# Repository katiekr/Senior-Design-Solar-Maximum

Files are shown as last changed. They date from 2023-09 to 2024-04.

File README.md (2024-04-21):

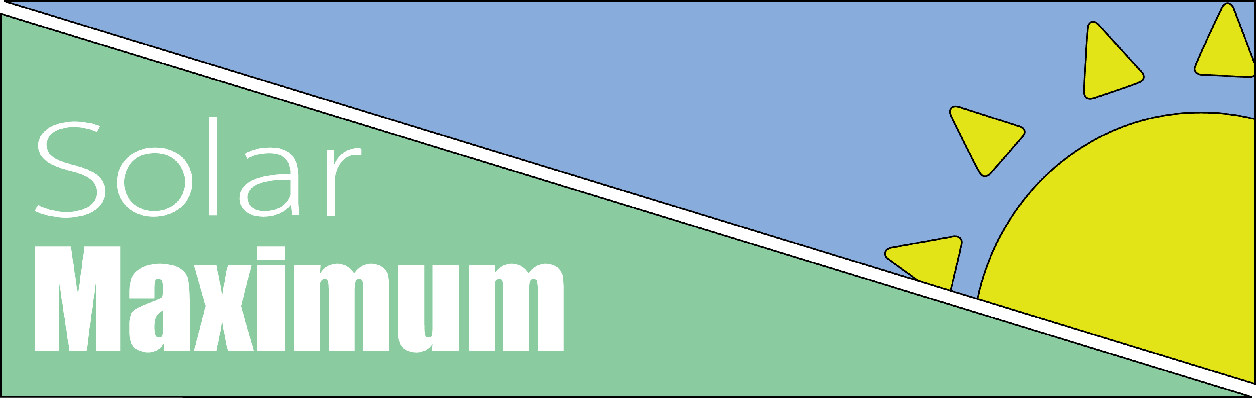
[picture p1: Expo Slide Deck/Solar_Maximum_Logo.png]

# Senior-Design-Solar-Maximum
[Team names (include Advisor) and Project Abstract](https://github.com/cabledc/Senior-Design-Solar-Maximum/blob/main/Team%20Info/Project%20and%20Group%20Members.md)

Project Description: Suntracking based on current input from a solar panel.

## First Semester

[Professional Biographies](https://github.com/cabledc/Senior-Design/tree/main/Biographies)

[User Stories](https://github.com/cabledc/Senior-Design/blob/main/Design/User_Stories.md)

[General Design Diagrams](https://github.com/cabledc/Senior-Design/tree/main/Design)

[Old Circuit Design Diagrams](https://github.com/cabledc/Senior-Design/tree/main/Design/Circuits)

[Project Tasks and Timeline (First Semester)](https://github.com/cabledc/Senior-Design/blob/main/Planning/Tasklist.md)

[ABET Concerns Essay](https://github.com/cabledc/Senior-Design/blob/main/Planning/Constraints%20(Assignment%207))

[PPT Slideshow Presentation (First Semester)](https://youtu.be/Y3RMfyllHsM)

[Self-Assessment Essays](https://github.com/cabledc/Senior-Design/tree/main/Team%20Info/Individual%20Capstone%20Assessments)

## Second Semester

[Updated Circuit Design Diagrams](https://github.com/cabledc/Senior-Design-Solar-Maximum/tree/main/Design/Circuits/Updated)

[Final Slideshow](https://www.youtube.com/watch?v=uT7PXCWO-sI)

[Expo Poster](https://github.com/cabledc/Senior-Design-Solar-Maximum/blob/main/Expo%20Slide%20Deck/Poster/Final%20Poster.pdf)

[Testing and Video Demos](https://github.com/cabledc/Senior-Design-Solar-Maximum/tree/main/Testing%20Logs)

[Budget](https://github.com/cabledc/Senior-Design/blob/main/Planning/Budget)

[Final Self-Assessments](https://github.com/cabledc/Senior-Design-Solar-Maximum/tree/main/Team%20Info/Self%20Assessments)

[Appendix and Committed Hours](https://github.com/cabledc/Senior-Design/blob/main/Planning/Appendix.md)

### User Documentation
[Hardware Setup (Start Here)](https://github.com/cabledc/Senior-Design-Solar-Maximum/blob/main/User%20Documentation/Hardware%20Setup.md)  

[Software Setup](https://github.com/cabledc/Senior-Design-Solar-Maximum/blob/main/User%20Documentation/Software%20Setup.md)  

[3D Printed Motor/Panel Adapter](https://github.com/cabledc/Senior-Design-Solar-Maximum/blob/main/User%20Documentation/3D%20Printed%20Housing%20Setup.md)  

[FAQ](https://github.com/cabledc/Senior-Design-Solar-Maximum/blob/main/User%20Documentation/FAQ.md)

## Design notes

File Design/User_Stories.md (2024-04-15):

- As the lead engineer for a green energy company, I want our solar panels to track the sun's position, so we can maximize the energy output and efficiency per panel.

- As a solar energy customer, I have limited area for a solar panel installation, so the panels should get as much sunlight as possible throughout the day.

- As a material scientist, I need ways of increasing output of our current solar cells, without using more expensive materials.

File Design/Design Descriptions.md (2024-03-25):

## Design Diagram Descriptions

## Design 1 Simple diagram of the system loop
  - Input 
    - Solar energy
  - Output
    - Panel Orientation

## Design 2 Shows computation and energy storage integration
  - Input 
    - Solar energy
    - Arduino
    - battery
  - Output
    - Arduino
    - Panel Rotation
    - Battery

## Design 3 Shows computation the algorithm inputs and outputs, energy storage and management, and how the feedback loop operates.
  - Input
    - Solar energy
    - Electricity measurement to arduino
    - Arduino
    - Battery
    - Charge Controller

  - Output
    - Arduino
    - Positioning/Tracking Algorithm Output
    - Panel Rotation
    - Feedback loop that maximizes solar energy
    - Battery
    - Charge Controller

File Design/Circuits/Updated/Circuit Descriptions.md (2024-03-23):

### Here you will find iterative circuit designs to progress testing our hardware components. These include: ###
- Testing the Current Reader Adafruit INA219 5v, which is the most important component, as it is getting data from the solar panel's current. We need to insure it is sensitive enough to detect changes in current.
  - >Note: ACS712 5v was tested in the old diagrams, it was not sensitive enough for accurate data.
- Testing the stepper motor. This is to get an initial positioning algorithm working, and see how different steps correspond to the angle of rotation.
  - >Note: steppers replaced servos because of the rotation limits on servos, as well as the lack of rotational accuracy.
- Testing with final prototype, this tests the charge controller and powers everything without a pc hookup.

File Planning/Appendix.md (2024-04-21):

# (Senior Design Part 1)
## What has been done:
  ### Hardware
  All the correct hardware has been acquired and the circuits have been designed. The hardware has been researched to match the specs of our design, (voltage, wattage, etc).
- We have found we needed a charge controller instead of connecting a battery directly to the solar panel. Otherwise this would have damaged the battery.
- Stepper motors were switched for servo motors. As stepper motors require constant charge, even when not moving. They also each require a control board making the circuit more complicated.
- Powering arduino components from the charge controller, instead of the arduino directly. Servo motors can spike in amps and potentially cut power from the arduino. Connecting everything to the main power supply (charge controller) prevents this.
- The Current reader applies zero load, so the initial circuit would have shorted and damaged the panel. A 220ohm resistor + LED was added for a load to prevent this.

  ### Software
- We have found supporting libraries exist for the arduino components we are using. These can be imported to allow faster interfacing with the components
  - Research on PID implementation. This will smooth jumpy/uneven output from an algorithm that is adjusting servo position(s).

### What still needs to be done next semester (In Order):
- Hardware prototype assembly.
- Arduino software implementation. And initial component interface testing.
- Each circuit (already designed) will be tested. There are 3, each one is more complex, but allows for a step by step process for testing. Leading to the final circuit.
- 3D printing of housing for the prototypes, if needed.

# (Senior Design Part 2)
### Hardware
After testing servo motors, we realized they cannot do a full 360 degree rotation. There was also no way to keep an accurate measurement of their movement. So we had to switch back to using a stepper motor instead. This allows us to keep track of steps and store information on energy recieved in each direction. As well as providing info for an untangle function.

We switched to Adafruit INA219 for current measurement as it provided higher resolution data, and allowed the device to work indoors with a flashlight. The ACS712 module was not sensitive enough for the low voltages we were using. More info can be found in the testing log summary [Current Testing](https://github.com/cabledc/Senior-Design-Solar-Maximum/blob/main/Testing%20Logs/Testing%20Logs%202-14-22.md)

The circuit diagrams had to be updated as well and can be found here [Updated Circuits](https://github.com/cabledc/Senior-Design-Solar-Maximum/tree/main/Design/Circuits/Updated)

A 3D printed holder for the solar panel and stepper motor mount was created. Those files can be found here [3D Prints](https://github.com/cabledc/Senior-Design-Solar-Maximum/tree/main/3D%20Printer%20Files)

### Software
3 Versions of the software are provided along with the testing for the deprecated ACS712 module (switched for Adafruit INA219). Each tracking code release improves on the previous version. The algorithm does not use a PID controller as this didn't quite fit the data and scenario we were trying to use it for. There are 3 main variables that control the new algorithm:
- int addSteps = 2;
  - Positive feedback when the rate of increase is greater than the previous rate of increase, adds steps to move the panel further in its current direction
- int divideSteps = 4;
  - Negative feedback when the rate of increase is less than the previous rate of increase, divides steps to slow the panels movement and increase measurement frequency. Once this is less than 2 the panel stops.
- int startingSteps = 40;
  - Initial movement check, in each direction. A full rotation is 2048 steps.

---
 
### Overall Listed Objectives Summmary:
- General design and project outline(October)
- Hardware planning and research(November)
- Circuit Design (December)
- Build first test prototype(February)
- Interface components with Arduino IDE(February)
- Mechanical Prototype Development/Testing(End of February)
  - Testing sensors, software calibration and filtering of raw data from the sensors.
  - Ensuring all components are tested and operate correctly and accurately
- Arduino Software Development(March)
  - Use the filtered sensor data to develop code to move the stepper with the attached solar panel

---

### Work Division (Second Semester)
> Destry Cable 91hrs
- Prototype Devlopment 86hrs
  - 3D Printing 8hrs
  - Circuit Redesign 10hrs
  - Code Development 30hrs
  - Testing 30hrs
  - Soldering and wire management 8hrs
- Expo Presenting 5hrs
    
> Katherine Kraus 45hrs
- Testing Planning 15hrs
- Slides and Presenting 10hrs
- Expo Presenting 5hrs
- Meetings/Communication 10hrs
  
> Alexander Miller 45hrs
- Logo and Poster Design 25hrs
- Meetings/Communication 10hrs
- Expo Presenting 5hrs

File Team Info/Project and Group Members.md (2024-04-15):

## Team Members
> Destry Cable - cabledc@mail.uc.edu

> Katherine Kraus - krauskr@mail.uc.edu

> Alexander Miller - mille8ae@mail.uc.edu

> Acting Advisor - Prof Zhao Yu

## Project Abstract
Our senior design project focuses on enhancing solar energy efficiency through a sun tracking system controlled by Arduino. By continuously adjusting solar panel orientation to follow the sun's path, our project aims to optimize energy output. 
We will develop an Arduino based control system that calculates the sun's position, while a mechanical system with sensors ensures accurate alignment. We will also implement energy monitoring and data logging to assess system performance. 
This project seeks to make solar power more efficient, contributing to sustainable energy solutions.

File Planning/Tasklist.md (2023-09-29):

|Project Tasks|  |Assigned Members|  |Date|

-Task 1           Katherine           10/15/23
Research Motors for tilt and rotation

-Task 2           Katherine           10/15/23
Research Battery needed

-Task 3           Katherine           10/15/23
Research Solar Panel needed
(5x5 inches max)

-Task 4           Katherine           10/15/23
Research component(s) for measuring electricity input on the arduino

-Task 5           Katherine           10/22/23
General circuit design and components
Create a detailed circuit design file with all the components included

-Task 6           Destry              10/29/23
Get tools needed, order components

-Task 7           Alexander,Destry    11/5/23
Arduino program outline 
Algorithm for moving motors based on input
PID inputs and use if needed
Feedback loop design

-Task 8           Destry              11/12/23     
Assembly of circuit and components
soldering etc.

-Task 9           Destry              11/19/23
3D printing housing and design
Programs needed, and types of files used

-Task 10          Alexander,Destry,Katherine  11/26/23
Final testing and refinement
Testing and refining arduino code on assembled components
Refining/optimizing various components

-Task 11          Alexander,Destry,Katherine  End of Semester
Final Presentation
Slides and recording

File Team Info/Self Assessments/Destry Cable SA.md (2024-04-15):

My individual contribution to this project was being the team leader/manager, and
 lead developer. I was responsible for developing the code base for the software. This
 includes filtering data input and developing the algorithm to feed the data into. Which
 controls the solar panel position by applying input to the stepper motor.
 
 The skills I built upon were learning how to interface with hardware through
 arduino code. Designing circuits, which I had little experience in. As well as getting a
 better understanding of how solar panels operate. This includes an understanding of
 how their electrical data output correlates with their position to a light source. I ran into
 many issues during the project. They were all hardware related. Some examples
 include the initial current sensor used was not sensitive enough. The servo motors were
 also not accurate with positioning, which needed to be tracked for the algorithm to
 operate correctly. So these parts had to be swapped and the circuit completely
 redesigned.

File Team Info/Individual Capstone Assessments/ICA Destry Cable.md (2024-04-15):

**Individual Capstone Assessment**

**Destry Cable**

  For my capstone project, I wanted to mainly focus on applying software to control hardware. The second area of focus is around green energy. 
To deliver on these two areas of focus I decided on solar power and how to maximize it with software. My plan is to create a small solar device that can orient itself for maximum electricity output. 
It would consist of a solar panel, two motors for tilt and rotation, an arduino as the computer, a battery to store power for the components, and an electricity meter. 
The arduino code would utilize a proportional–integral–derivative controller or PID to control the movement for both of the motors, using input from the electricity meter.

  PIDs are very useful for outputting a smooth control, as adjusting the motors would likely be jittery/jumpy without one. 
The concepts of PIDs can be applied from Calculus 1 and 2. I have used a PID in arduino code to control a robot solving a maze in my sophomore year. 
I recall the class was ENED1120. It was effective for keeping the robot from over/under correcting its movement. I quite enjoyed this project in this class and wanted to do something similar with using hardware/robotics for my senior project.

  My Co-op experiences consisted of working for Honeywell Intelligrated as an VR/AR (virtual and augmented reality) software engineer. At this co-op I did VR work for training software. 
This software is used to train employees how to operate conveyor and logistical sorting systems. I also worked on simulation software that can take autocad files of conveyor systems and convert them into a working warehouse simulation. 
Simulating, sorting systems, movement of boxes, etc. All of this work was mainly software focused, and did not apply directly to robotics/hardware, but it did simulate it.

  This ties into my senior project motivation. As my co-op was all software engineering. I want to challenge myself and try working more with hardware, since it’s something I haven’t had another opportunity to do. 
I gained experience working with software such as Autocad, blender, Unity 3D at my co-op which I will use for 3D printing parts. I haven’t used a 3D printer before but this project and knowledge of 3D software will give a good excuse to learn how to use one. 
I could even simulate parts of this project using the same software I used at my Co-op if I really needed to.

  To approach this project I would likely start with taking two motors (or a two axis motor), and hook it up to an arduino. This would allow me to get the basics for controlling the motors through an arduino before introducing the other components. 
The second step would be getting some kind of electricity meter and solar panel and testing the feedback through the arduino. The next step would be setting up the PID controller code to receive the electricity input. 
The end result of this project is for it to track the sun's position. There’s a chance it could use more electricity adjusting itself, nullifying any efficiency gains from tracking the sun. 
This could be tested with a control, with a stationary solar panel. Even if it fails in efficiency it’s still a proof of concept and I’d be happy with just getting the basics of it working.

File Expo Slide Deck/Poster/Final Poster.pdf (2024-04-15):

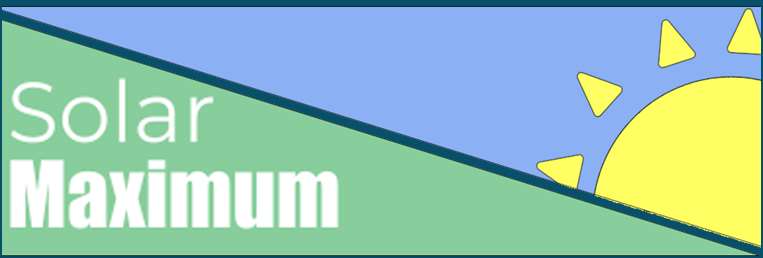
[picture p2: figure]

## Destry Cable

## Alexander Miller

## Katherine Kraus

## Advisor: Prof Zhao

Yu

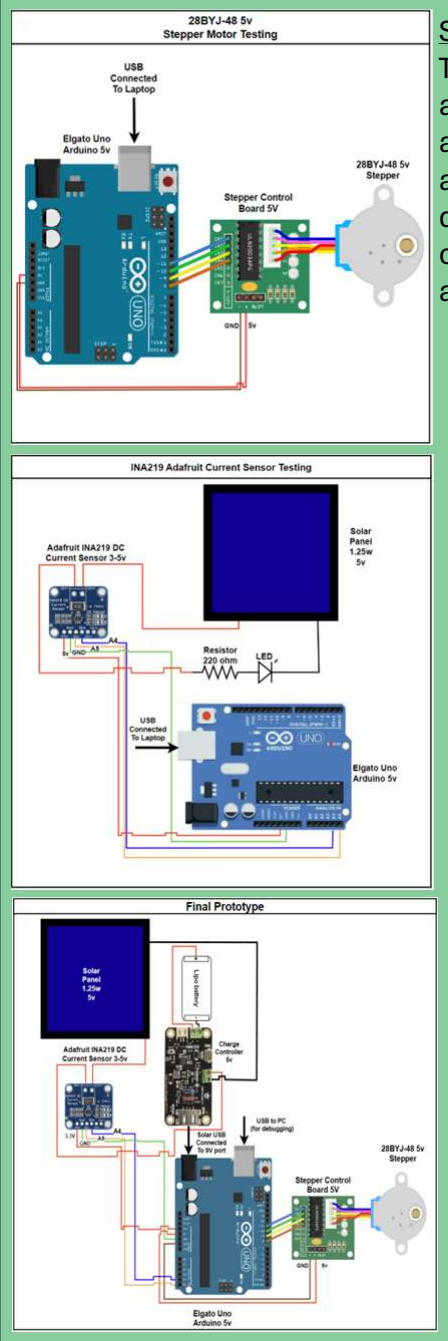
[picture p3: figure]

Stepper Testing:
Testing the motor
and initial positioning
algorithm as well
as determining how
different steps
correspond to the
angle of rotation.

Current Testing:
Testing the Current
Reader Adafruit
INA219 5v and
insuring it is sensitive
enough to detect
changes in current.

Final Diagram:
Testing the charge
controller and power
without a pc hookup

Our senior design project focuses on enhancing solar energy efficiency through a sun tracking system controlled by Arduino. By continuously adjusting solar panel orientation to follow the sun's path, our project aims to optimize energy output. We will develop an Arduino based control system that calculates the sun's position, while a mechanical system with sensors ensures accurate alignment. We will also implement energy monitoring and data logging to assess system performance. This project seeks to make solar power more efficient, contributing to sustainable energy solutions. • Enhance Solar Energy Efficiency

- This project aims to increase and optimize the efficiency of Solar Energy devices to produce the most amount of energy possible without depleting resources back into the machine
- Automation and Integration
- The nature of this project is a hybrid integrated software/hardware device to automate Solar Array positioning for increased operation efficiency
- Sustainable Energy
- This project will be able to benefit the greater good by potentially optimizing the energy produced by solar cell systems to provide better pathways for future energy production.

### Project Overview

### Purpose and Goals

System Loop

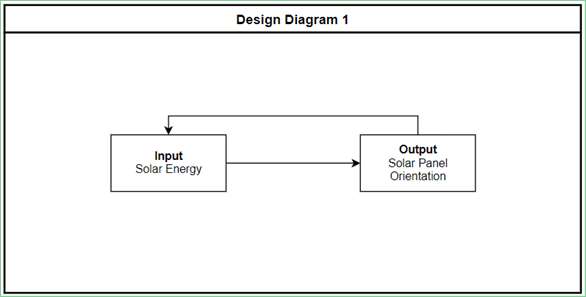
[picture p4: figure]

Computation and Energy Storage Integration

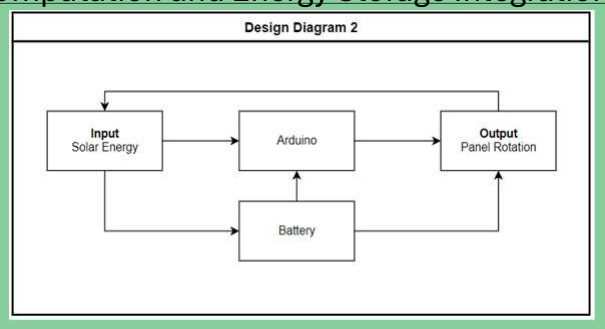
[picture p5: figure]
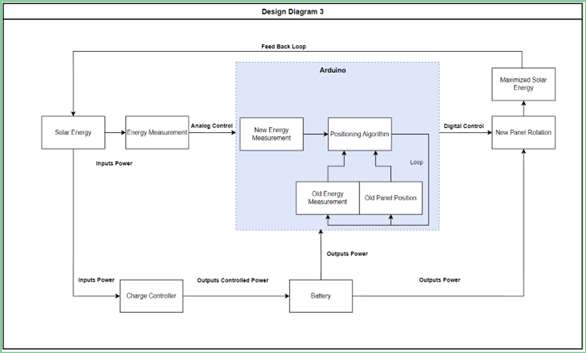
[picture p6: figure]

Full System Algorithm

### Software and Electrical Design Diagrams

The following designs outline the computation
and algorithm inputs and outputs, energy
storage and management, and how the feedback loop operates.

### Hardware Testing Diagrams

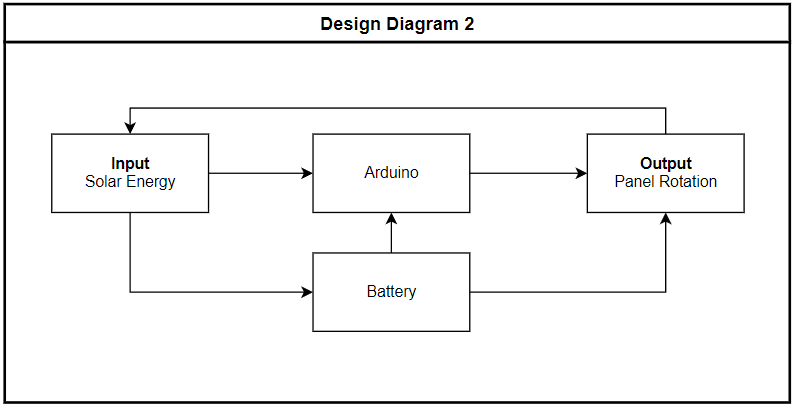
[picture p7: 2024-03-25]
Design/D2.PNG

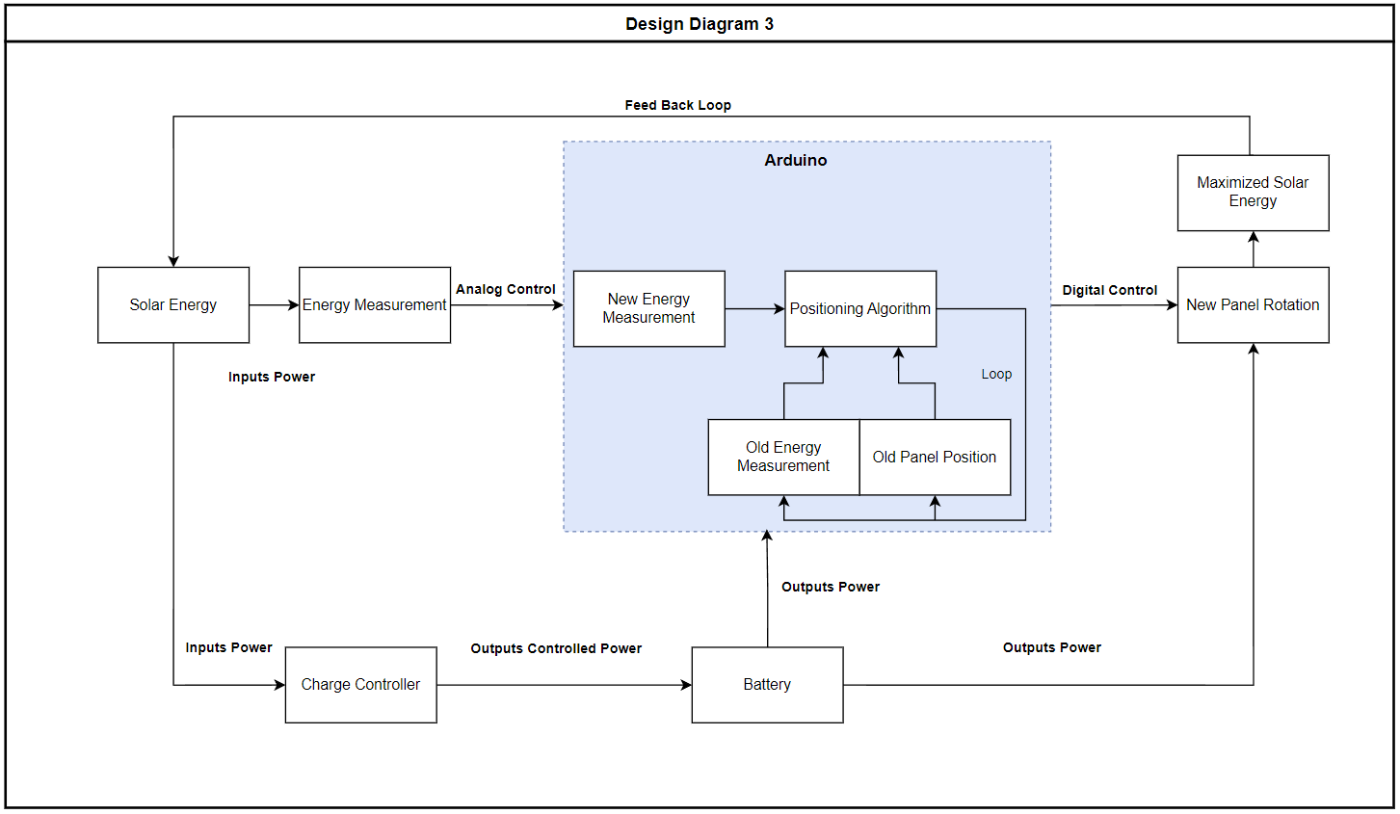
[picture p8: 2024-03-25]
Design/D3.PNG

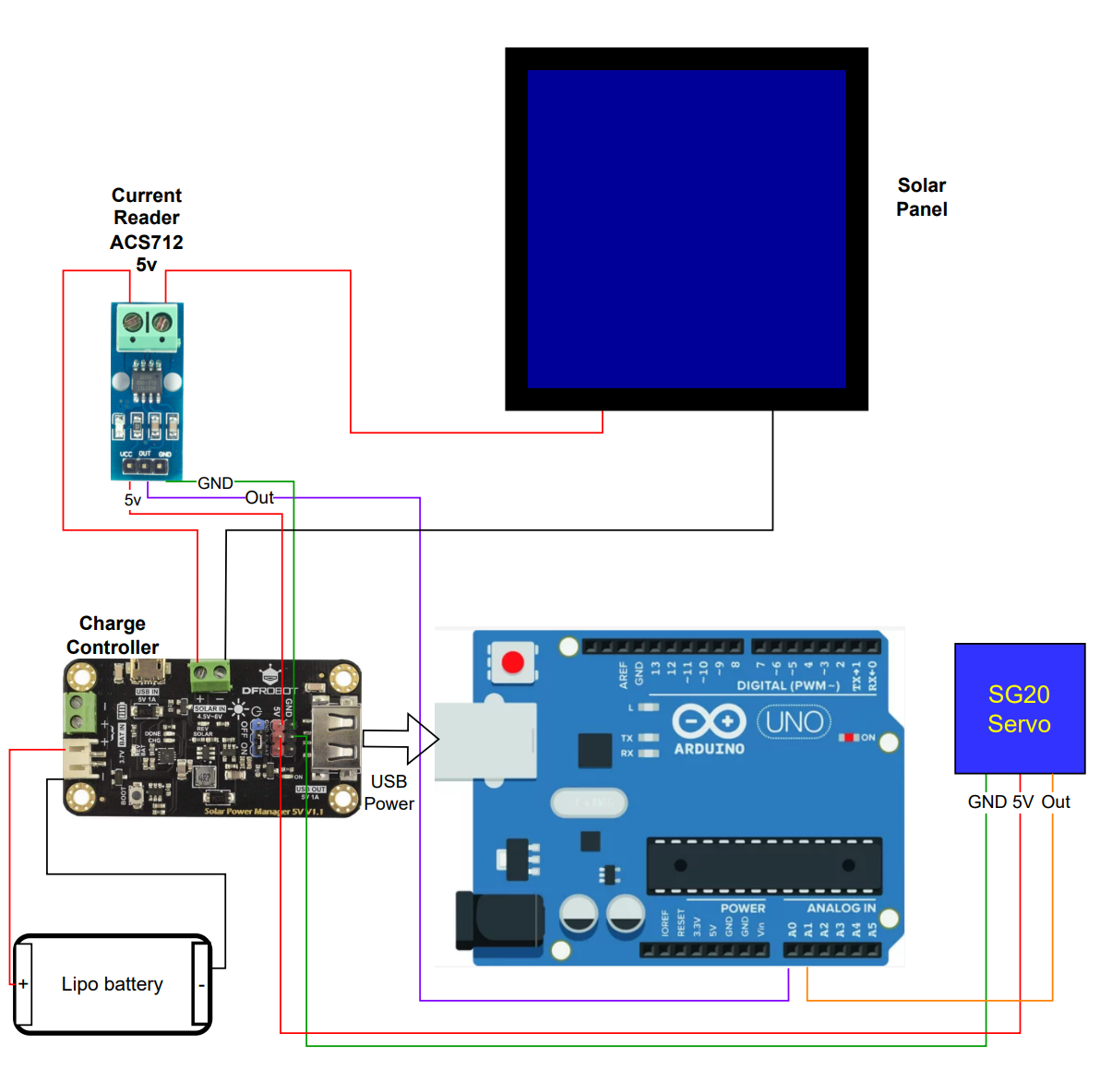
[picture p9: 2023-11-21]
Design/Circuits/Arduino_Diagram_1_Servo.PNG

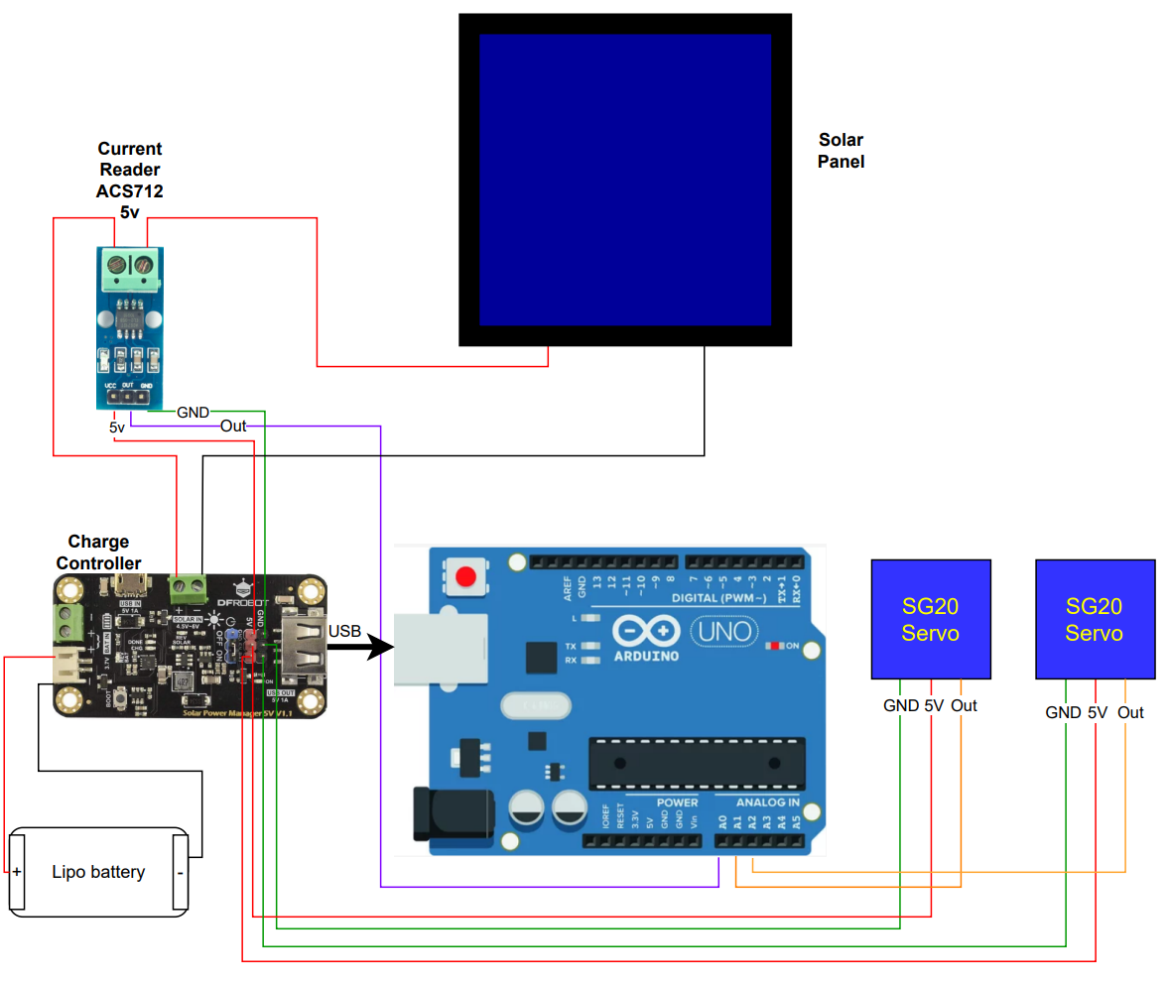
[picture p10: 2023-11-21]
Design/Circuits/Arduino_Diagram_2_Servos.PNG

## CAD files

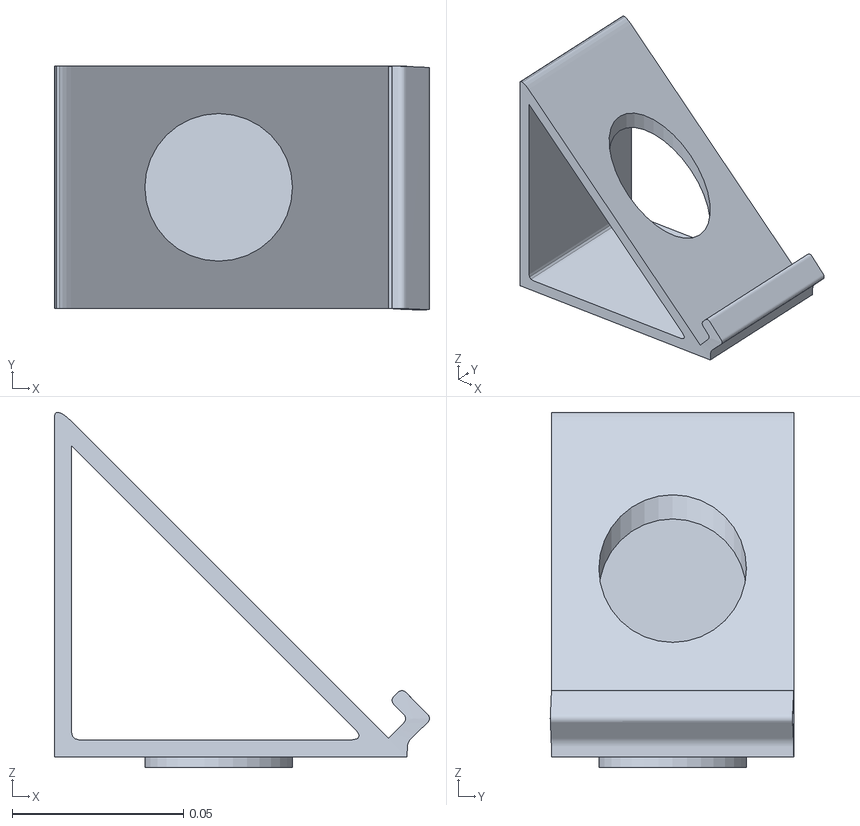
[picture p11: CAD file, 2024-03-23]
3D Printer Files/Solar_Panel_Mount_Final_2.stl
0.109 x 0.071 x 0.104

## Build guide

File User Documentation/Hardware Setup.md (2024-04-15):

# Hardware Setup

## Components needed
- DC 5V to DC 9V USB Voltage Step Up Converter Cable 
- 28BYJ-48 Stepper Motor and motor control board
- ELGATO UNO R3 Compatible with Arduino IDE or an Arduino R3 equivalent board
- Sunnytech 0.5w 5v 100ma Mini Small Solar Panel Module DIY Polysilicon Solar Epoxy Cell Charger B016 or an equivalent 0.5w 5v 100ma solar panel
- INA219 adafruit Module Compatible for Arduino
- 3.7V Lithium ion Battery 1100mAh 603449 Rechargeable 3.7 Volt Lipo Battery Pack or an equivalent battery pack
- 900mA MPPT Solar Panel Controller
- Wiring for connecting components
- Male to male Usb connector for the Arduino board (for installing software and connecting the charge controller) This should come with the Arduino board
- A computer or laptop than can run Arduino IDE
- Access to a 3D printer to mount the solar panel to the stepper motor. (You can improvise and make your own if you don't have access to a 3D printer)
- A mounting platform such as a piece of wood and wood screws

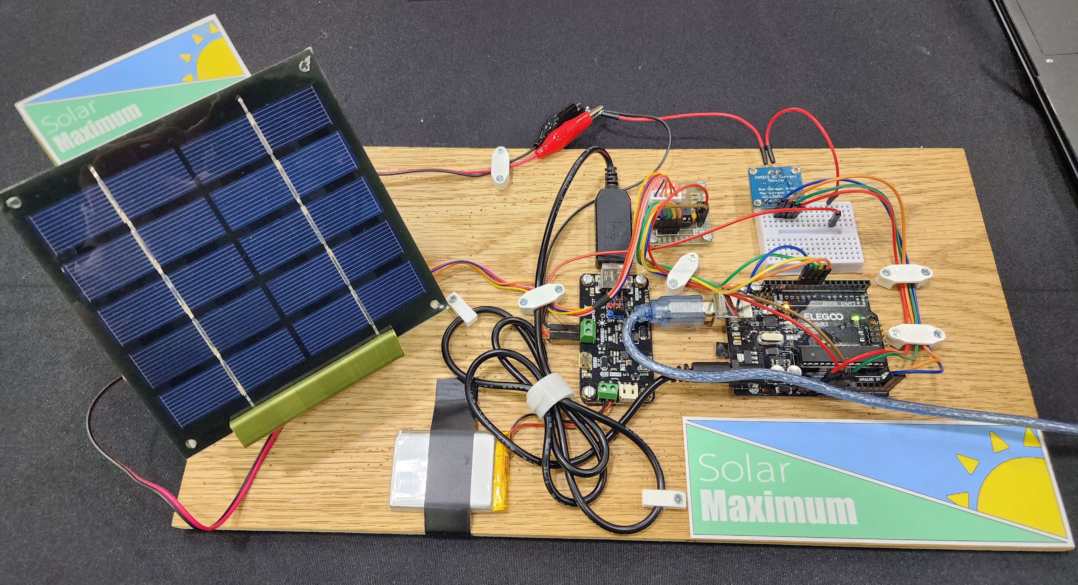
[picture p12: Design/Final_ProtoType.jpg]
Finished Build


## Circuit Setup
The circuit below represents the final prototype wiring. Some components such as the INA219 adafruit Module might need to be soldered together, this depends on where you order the part. 

When installing the software plug the arduino into the pc through the usb port. When finished, disconnect from the PC/Laptop and make sure the charge controller is plugged into the 9v port in the arduino. 

Note: You can keep the laptop plugged in for debugging if needed. 

If no data is being printed to your debug logs, your current sensor likely isn't working, or connected correctly. A debug log should appear "Failed to find INA219 chip" if this is the case.

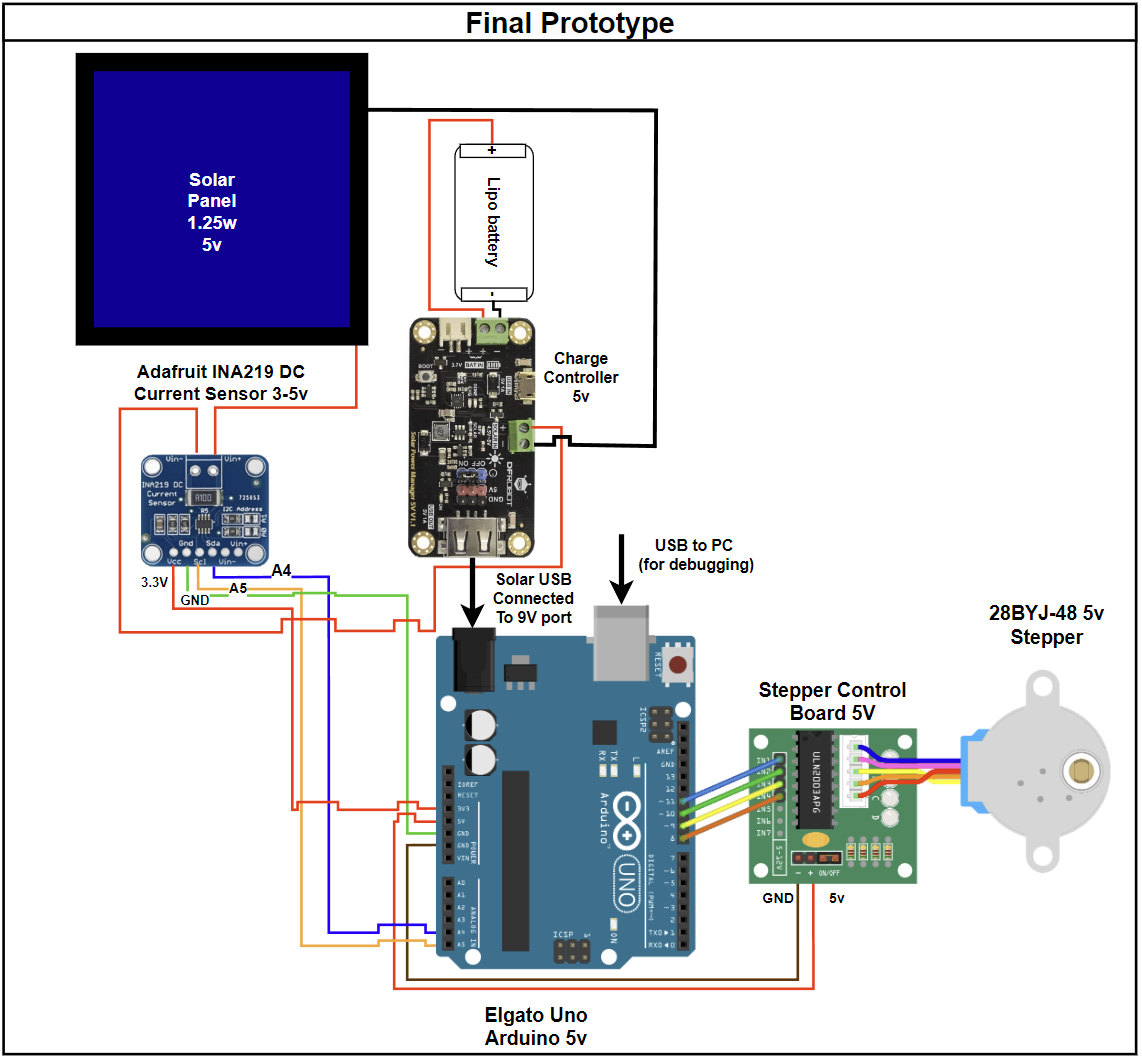
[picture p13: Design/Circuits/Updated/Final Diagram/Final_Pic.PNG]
Circuit


>[Return](https://github.com/cabledc/Senior-Design-Solar-Maximum/tree/main?tab=readme-ov-file#user-documentation)

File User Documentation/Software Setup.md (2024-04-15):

# Software Setup

## PC/Laptop IDE
- [Download Arduino IDE here](https://www.arduino.cc/en/software)
- Unzip the folder and run the .exe to install the IDE
- Open the IDE go to Sketch>Include Library and select "Adafruit INA219" from contributed libraries
  - If it does not show up go to Sketch>Include Library>Manage Libraries and search "Adafruit INA219" select it and install

## Download and Setup of Solar Arduino files (WIP)
- [Download the Solar Maximum arduino file here](https://github.com/cabledc/Senior-Design-Solar-Maximum/blob/main/Codebase/Tracking_3_Panel_Stepper_Enhanced_Bidirectional_Final.ino)
- [Arduino documentation for uploading the sketch files to your board](https://support.arduino.cc/hc/en-us/articles/4733418441116-Upload-a-sketch-in-Arduino-IDE)

> [Return](https://github.com/cabledc/Senior-Design-Solar-Maximum/tree/main?tab=readme-ov-file#user-documentation)

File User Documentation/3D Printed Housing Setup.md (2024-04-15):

# 3D Printed Solar Panel Motor Mount
## Files for 3D Printing
- Can be found [here](https://github.com/cabledc/Senior-Design-Solar-Maximum/tree/main/3D%20Printer%20Files)

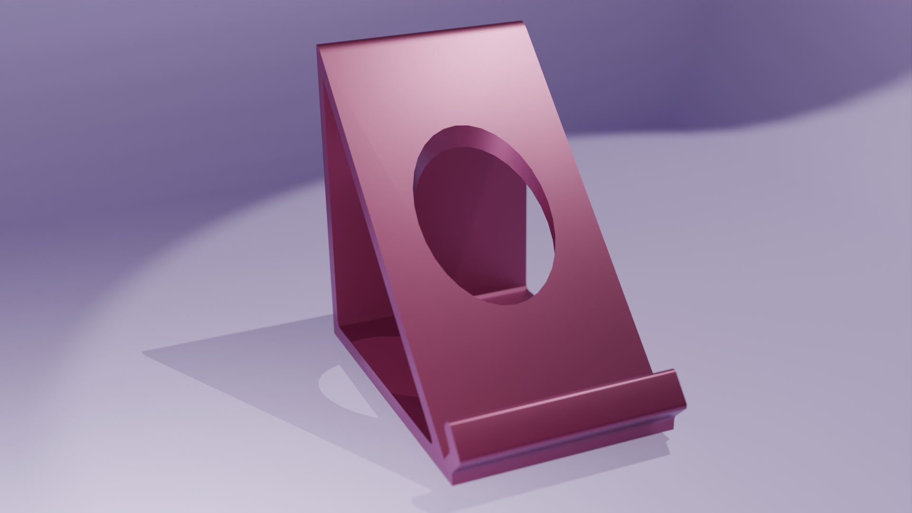
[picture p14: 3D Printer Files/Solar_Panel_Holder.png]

> [Return](https://github.com/cabledc/Senior-Design-Solar-Maximum/tree/main?tab=readme-ov-file#user-documentation)

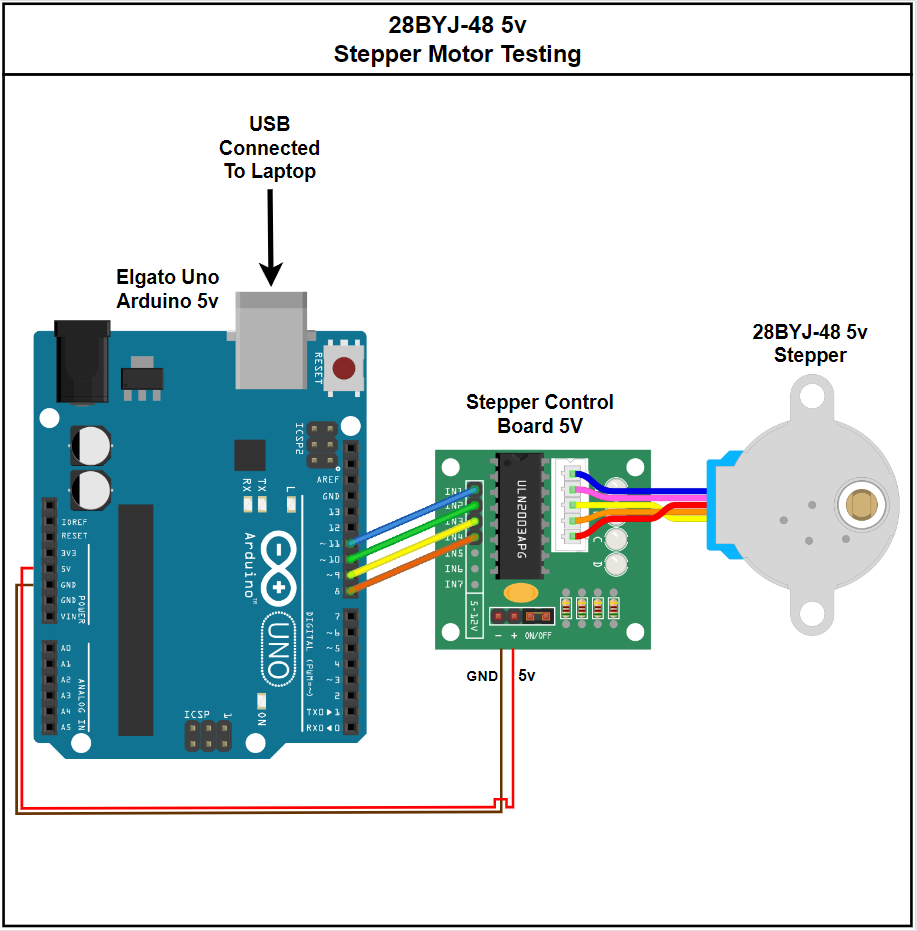
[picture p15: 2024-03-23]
Design/Circuits/Updated/Stepper Testing/Step_Pic.PNG

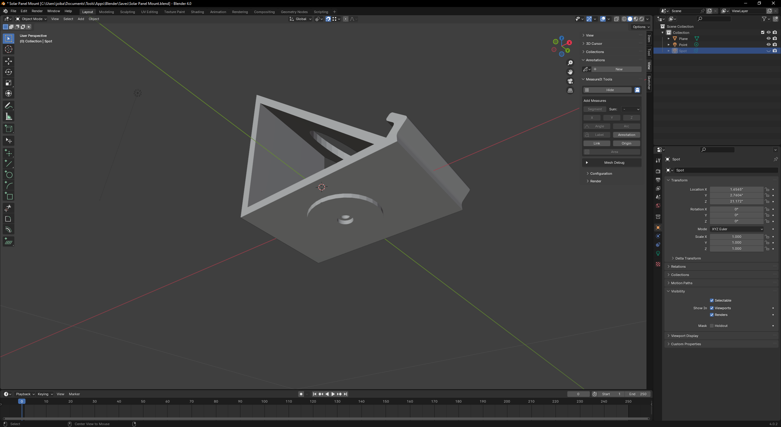
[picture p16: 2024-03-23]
3D Printer Files/Pre_render_Bottom.png

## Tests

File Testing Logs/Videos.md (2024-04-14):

## Current Sensor testing with Adafruit INA219
Current Sensor Testing (https://www.youtube.com/watch?v=yIj-4R2wbA0 "Current Sensor Testing")

## Solar Panel Testing Indoors, testing tracking code
Solar Panel Testing Indoors (https://www.youtube.com/watch?v=Y-p1hI5SreM "Solar Panel Testing Indoors")

## Final Tracking Code Demo at EXPO
Solar Panel EXPO DEMO (https://www.youtube.com/watch?v=vK8msLIR4Fc "Solar Maximum CEAS Expo Demo")

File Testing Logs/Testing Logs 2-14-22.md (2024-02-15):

> 2/14/22
> ## Current module testing
- ACS712 module testing with 220ohm resistor and blue LED (3.5v) showed very little variation in current in indirect sunlight vs indoors (5pm).
  
    The load might need to be increased for more current draw, so the ACS712 current sensor can hopefully detect variations more accurately.
    Further testing might be needed with the charge controller and battery, which is in diagram one but with the servo absent.
  
    Charging the battery should provide sufficient load. **However if the battery is full, the current will drop and the solar panel will stop adjusting for an optimal position until the battery starts depleting.
    This might be beneficial to prevent overcharging and increase effeciency, as the panel would only start moving again when the battery is not full.** Further testing with a servo will be needed to confirm this though.  

- **The bit resolution of the arduino board might be a limiting factor** using the hall effect from ACS712, which has no onboard processing and requires the user to implement code to convert to mA and is analog to analog at 10bits. This data is processed by the Arduino directly.
  
    Adafruit INA219 uses a different method for measurement. Through a "shunt resistor" and an **onboard processing resolution of 12bits** to directly output current(mA), voltage(mV), and power(mW). These values are digital on the INA219 board, then directly output to analog to the arduino, **bypassing the 10bit processing limit**. As the arduino is not doing the processing, only recieving processed values from the INA219 board.
  
- **ACS712 has a current resolution of 75mA while the Adafruit INA219 has a resolution of 0.08mA.** So it will probably be switched as the main sensor if testing proves this increase in accuracy.
- A few other issues encountered with the ACS712 module occurred when it was moved or bumped (not the solar panel), and resulted in large current fluctuations. Since the solar panel will be moving on a servo this could pose issues for excessive noise and calibration difficulties.
- To be thorough 4 ACS712 modules were swapped and tested, they all showed similiar issues mentioned above. This rules out manufacturing errors or bad modules.
- I've ordered 4 INA219 modules and will be testing these when they arrive this week.

> ## Solar Charge Controller Testing
- Polarity of the Lipo battery plug did not match the port on the charge controller, so the plug was cut and the wires were stripped to be connected in the onboard two pole connector.
- Interfacing with the arduino on a PC was possible while it was being powered with the charge controller and lipo battery connected.

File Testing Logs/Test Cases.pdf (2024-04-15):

## Senior Design Test Plan

Overall Test Plan: Our general testing strategies employed by our project are hardware performance, software to hardware integration, then algorithm optimization. First we will test if the hardware used is working correctly. Going through each circuit design outlined. Once the hardware is confirmed to have no physical issues, we will test integration of the arduino libraries for each component. Ensuring they can communicate with the arduino components properly. We will then move on to algorithm optimization for moving the solar panels.

### Initial Testing of Hardware

H1.1 Hardware Test 1 Current Reader
H1.2 We need to ensure it is sensitive enough to detect changes in current.
H1.3 Testing the Current Reader ACS712 5v, which is the most important component, as it is getting data from the solar panel's current.
H1.4 Inputs: Solar panel angles/orientation. Shade and sunlight
H1.5 Outputs/Expected Results: Current reader shows notable differences when solar panel is placed at different angles/orientation
H1.6 Abnormal Results: current differences are not detectable

H2.1 Hardware Test 2
H2.2 Testing with one servo motor
H2.3 Test our second circuit with one servo.
H2.4 Inputs: Arduino code to move the servo to various positions
H2.5 Outputs/Expected Results: Servo moves to code input and correct position H2.6 Abnormal Results: Servo stalls, or fails to move.

H3.1 Hardware Test 3
H3.2 Testing with two servo motors
H3.3 Testing with two servo motors. This is the diagram of our final circuit.
H3.4 Inputs: Arduino code to move the servos to various positions
H3.5 Outputs/Expected Results: Each servo moves to code input and correct position H3.6 Abnormal Results: Servos stalls, fails to move, or move incorrectly.

H4.1 Hardware Test 4
H4.2 How does the system behave when solar is obscured
H4.3 Testing for shade/ cloudy weather
H4.4 Inputs: Place in shade or overcast weather
H4.5 Outputs/Expected Results: The servos attempt to adjust to the optimal position H4.6 Abnormal Results: The device keeps readjusting or can’t find an optimal position.

H5.1 Hardware Test 6
H5.2 Find optimal rate of adjustment
H5.3 How fast the panel should adjust/update
H5.4 Inputs:Current reader data, Panel movement
H5.5 Outputs/Expected Results: Panel movement should be smooth and slowly adjust as needed
H5.6 Abnormal Results: jittery fast movement, constant adjustments.

H6.1 Hardware Test 7
H6.2 Rainy weather
H6.3 Test for waterproofing
H6.4 Inputs: Rain
H6.5 Outputs/Expected Results: Encased electronics are dry H6.6 Abnormal Results: Encased electronics are not dry

### Initial Testing of Software

S1.1 Software Test 1
S1.2 Testing if battery level is sustaining
S1.3 Can the battery sustain itself all day, output more than it inputs.
S1.4 Inputs: Electricity from the solar panel
S1.5 Outputs/Expected Results: Charged battery, battery is at a higher level than it started S1.6 Abnormal Results: Device dies during the day.

S2.1 Software Test 2
S2.2 Testing if position information is being recorded
S2.3 Test libraries for arduino servos
S2.4 Inputs: Servo position
S2.5 Outputs/Expected Results: Servo position matches position in code S2.6 Abnormal Results: Mismatch between logs and servo position

S3.1 Software Test 3
S3.2 How fast the panel should adjust/update (algorithm)
S3.3 For maximizing efficiency find the optimal rate for adjusting the panel throughout the day S3.4 Inputs: Current reader to Algorithm
S3.5 Outputs/Expected Results: Panel moves slowly enough to maximize battery life
S3.6 Abnormal Results: Panel kills battery early from moving too much.

S4.1 Software Test 4
S4.2 Panel movement if it’s smooth/jumpy etc. (algorithm)
S4.3 Test algorithm output
S4.4 Inputs: Current reader, servo’s last positions
S4.5 Outputs/Expected Results: Servos move smoothly S4.6 Abnormal Results: Servos have jittery/jumpy movement

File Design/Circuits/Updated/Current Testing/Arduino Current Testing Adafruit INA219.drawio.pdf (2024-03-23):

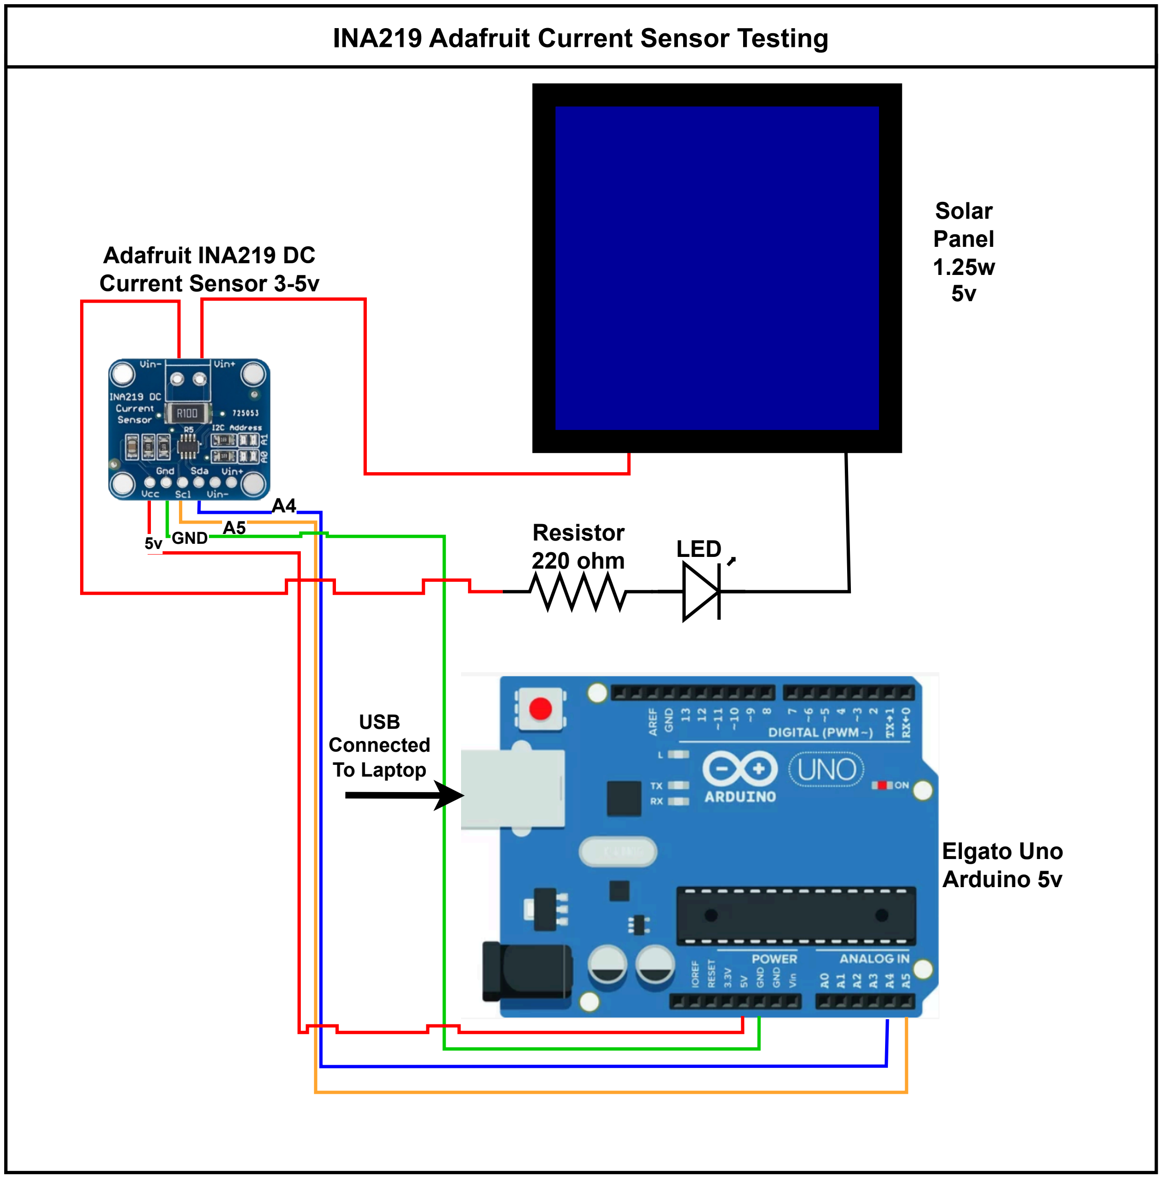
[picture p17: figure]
Adafruit INA219 DC Current Sensor 3-5v; Solar Panel 1.25w 5v; USB Connected To Laptop; Resistor; 220 ohm; LED ⁵v GND; Elgato Uno Arduino 5v; INA219 Adafruit Current Sensor Testing

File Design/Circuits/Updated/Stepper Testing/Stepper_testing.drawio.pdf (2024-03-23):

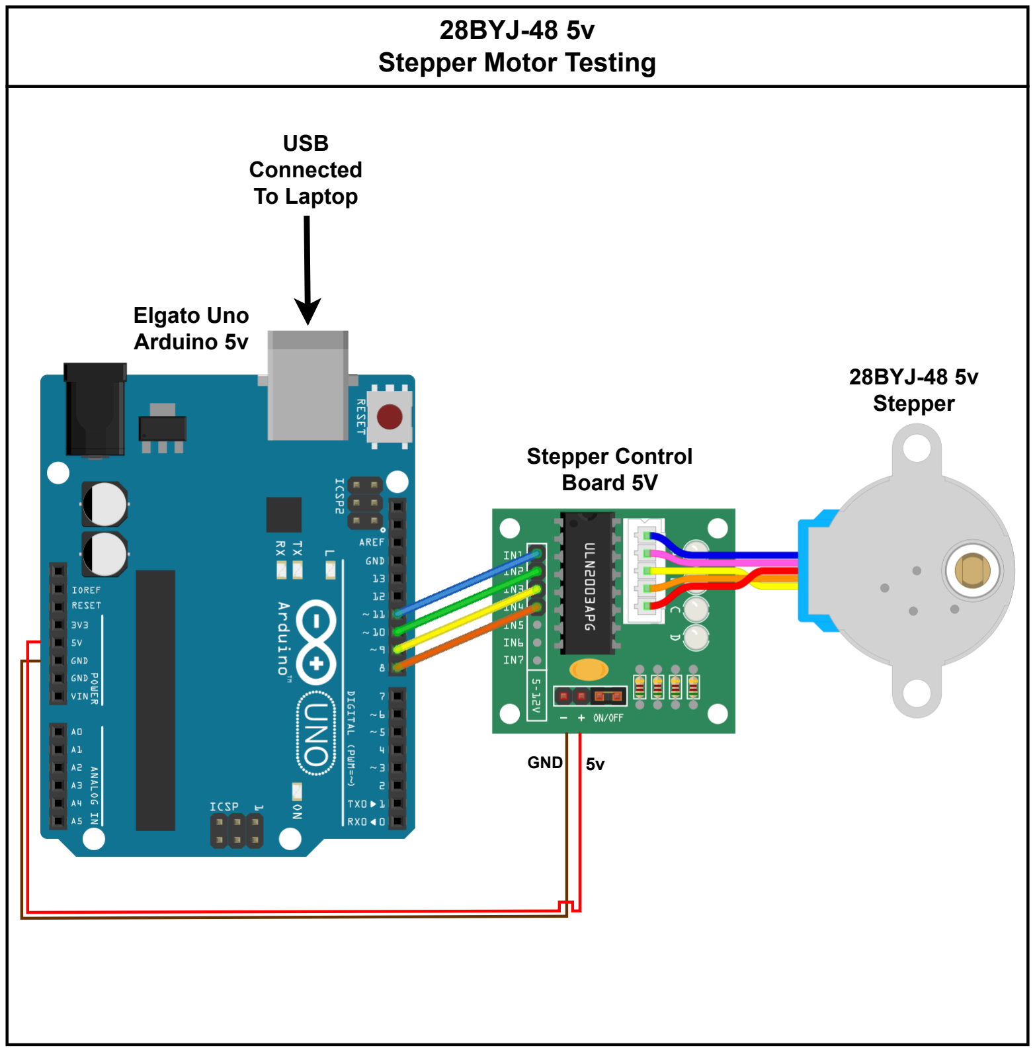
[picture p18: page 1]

### 28BYJ-48 5v Stepper Motor Testing

Elgato Uno
Arduino 5v

USB
Connected
To Laptop

Stepper Control
Board 5V

28BYJ-48 5v
Stepper

GND 5v

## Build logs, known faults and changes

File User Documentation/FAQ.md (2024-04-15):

## FAQ
> **Do I need to calibrate the device?**
> 
> > *No the device should calibrate on its own when place outside, ideally in a non obscured location.*
>   
> **What if the battery is dead when setting up the device?**
> 
> > *If the battery is completely dead the solar panel will still get sunlight, and eventually provide power to the battery and the device itself. It will eventually go through calibration and orient itself correctly.*
>   
> **Is the device waterproof?**
> 
> > *A housing is required for waterproofing the electronics. Exposing the board or wire connectors to the elements will likely damage it. This prototype does not include any housing.*
> 
> **Does my operating system matter for setup?**
> 
> > *Arduino IDE runs on Windows, Apple, and Linux systems. Select the corresponding download for your operating system.*
>
> **How can I edit the sketch file/code while the device is running?**
> > *One of the hardware components required is a DC 5V to DC 9V USB Voltage Step Up Converter Cable. This cable plugs into the arduino boards 9v port, and the usb into the solar controller. This frees up the usb port on the arduino allowing you to plug the entire device into your PC/Laptop for debugging and editing code*.

> [Return](https://github.com/cabledc/Senior-Design-Solar-Maximum/tree/main?tab=readme-ov-file#user-documentation)

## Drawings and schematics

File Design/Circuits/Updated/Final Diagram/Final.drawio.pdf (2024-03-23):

# Final Prototype

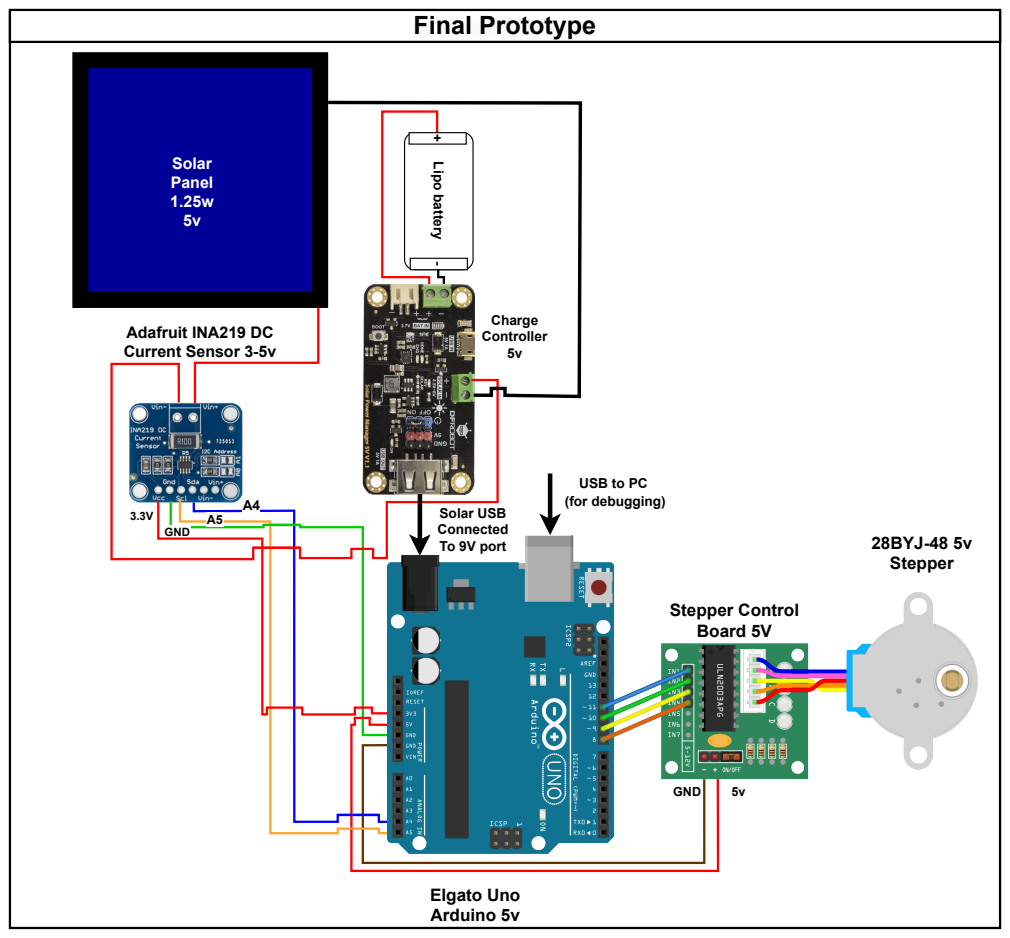
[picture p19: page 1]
Adafruit INA219 DC Current Sensor 3-5v; Solar Panel 1.25w 5v; Solar USB Connected To 9V port; GND; Charge Controller 5v; Lipo battery + -; 28BYJ-48 5v Stepper; Stepper Control Board 5V; Elgato Uno Arduino 5v

USB to PC
(for debugging)

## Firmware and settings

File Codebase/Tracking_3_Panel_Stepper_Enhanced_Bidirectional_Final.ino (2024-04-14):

#include <Stepper.h>
#include <Wire.h>
#include <Adafruit_INA219.h>

#define STEPPER_PIN_1 8
#define STEPPER_PIN_2 9
#define STEPPER_PIN_3 10
#define STEPPER_PIN_4 11

const int stepsPerRevolution = 2048;
Stepper myStepper(stepsPerRevolution, 8, 10, 9, 11);

Adafruit_INA219 ina219;

unsigned long time = millis();

struct positionData{
  int totalSteps;
  int bestLocationStep;
  bool skipClockwise;
  bool skipCounterClockwise;
  float maxReading;
  float counterClockwiseMax;
  float clockwiseMax;
  bool init;

};


struct averagePower{
 float current;
 float shuntVoltage;
 float busVoltage;
 float loadVoltage;
 float power;

 float oldCurrent;
 float oldVoltage;
 float oldPower;
};

averagePower avgPower;
positionData posData;
bool globalInit;

int addSteps = 2;
int divideSteps = 4;
int startingSteps = 40;

void setup(void) 
{
  Serial.begin(9600);

  //pinMode(STEPPER_PIN_1, OUTPUT);
  //pinMode(STEPPER_PIN_2, OUTPUT);
  //pinMode(STEPPER_PIN_3, OUTPUT);
  //pinMode(STEPPER_PIN_4, OUTPUT);
  myStepper.setSpeed(1);

  while (!Serial) {
      // will pause Zero, Leonardo, etc until serial console opens
      delay(16);
  }
    
  Serial.println("Hello!");
  
  // Initialize the INA219.
  // By default the initialization will use the largest range (32V, 2A).  However
  // you can call a setCalibration function to change this range (see comments).
  if (! ina219.begin()) {
    Serial.println("Failed to find INA219 chip");
    while (1) { delay(10); }
  }
  // To use a slightly lower 32V, 1A range (higher precision on amps):
  //ina219.setCalibration_32V_1A();
  // Or to use a lower 16V, 400mA range (higher precision on volts and amps):
  ina219.setCalibration_16V_400mA();
  

  Serial.println("Measuring voltage and current with INA219 ...");
}

void ReadCurrentSensor(){
  unsigned long startTime = millis(); // Store the start time
  unsigned long elapsedTime = 0; // Variable to keep track of elapsed time
  int samples = 0;



  bool printSensor = true;
  float shuntVoltage = 0;
  float busVoltage = 0;
  float current_mA = 0;
  float loadVoltage = 0;
  float power_mW = 0;

  float samplesSV =0, samplesBV =0, samplesC = 0, samplesLV = 0, samplesP = 0;

  // Enter the while loop that runs for 2 seconds and Filter data
  while (elapsedTime < 500) { // 500 milliseconds = 0.5 seconds
    shuntVoltage = ina219.getShuntVoltage_mV();
    busVoltage = ina219.getBusVoltage_V();
    current_mA = ina219.getCurrent_mA();
    power_mW = ina219.getPower_mW();
    loadVoltage = busVoltage + (shuntVoltage / 1000);

    samplesSV = samplesSV + shuntVoltage;
    samplesBV = samplesBV + busVoltage;
    samplesC = samplesC + current_mA;
    samplesLV = samplesLV + loadVoltage;
    samplesP = samplesP + power_mW;


    // Update the elapsed time
    elapsedTime = millis() - startTime;
    samples++;
  }

  //Update avgPower
  avgPower.shuntVoltage = samplesSV/samples;
  avgPower.busVoltage = samplesBV/samples;
  avgPower.current = samplesC/samples;
  avgPower.loadVoltage = samplesLV/samples;
  avgPower.power = samplesP/samples;

  //Instant Readings
  shuntVoltage = ina219.getShuntVoltage_mV();
  busVoltage = ina219.getBusVoltage_V();
  current_mA = ina219.getCurrent_mA();
  power_mW = ina219.getPower_mW();
  loadVoltage = busVoltage + (shuntVoltage / 1000);

/*
  //Filter data
  for (int x = 0; x < 150; x++){ //Get 150 samples
    shuntvoltage = ina219.getShuntVoltage_mV();
    busvoltage = ina219.getBusVoltage_V();
    current_mA = ina219.getCurrent_mA();
    power_mW = ina219.getPower_mW();
    loadvoltage = busvoltage + (shuntvoltage / 1000);
 
    samplesC = samplesC + current_mA;  //Add samples together
    samplesV = samplesV + loadvoltage;
  }
  avgLoadVoltage = samplesV/150.000;//Taking Average of Samples
  avgCurrent = samplesC/150.000;

  //Update avgPower
  avgPower.current = abs(avgCurrent);
  avgPower.voltage = avgLoadVoltage;
  avgPower.power = ina219.getPower_mW();
*/
  if(printSensor){
    Serial.print("BusVoltage:"); Serial.print(busVoltage,6); Serial.println(" V");
    Serial.print("ShuntVoltage:"); Serial.print(shuntVoltage,6); Serial.println(" mV");
    Serial.print("LoadVoltage:"); Serial.print(loadVoltage, 6); Serial.println(" V");
    Serial.print("Current:"); Serial.print(current_mA,6); Serial.println(" mA");
    Serial.print("Power:"); Serial.print(power_mW,6); Serial.println(" mW");
    Serial.println("");

    Serial.print("AvgBusVoltage:"); Serial.print(avgPower.busVoltage,6); Serial.println(" V");
    Serial.print("AvgShuntVoltage:"); Serial.print(avgPower.shuntVoltage,6); Serial.println(" mV");
    Serial.print("AvgLoadVoltage:"); Serial.print(avgPower.loadVoltage ,6); Serial.println(" V");
    Serial.print("AvgCurrent:"); Serial.print(avgPower.current,6); Serial.println(" mA");
    Serial.print("AvgPower:"); Serial.print(avgPower.power,6); Serial.println(" mW");
    Serial.println("");
  }
}

void loop(void) 
{
  /*
  float tempReading;
  float maxThreshold = 0.20;
  float maxReading = posData.maxReading - (posData.maxReading * maxThreshold);

  ReadCurrentSensor();
  tempReading= (avgPower.current*avgPower.loadVoltage+(avgPower.power*2));
  
  if(maxReading > tempReading && globalInit == false){
    Serial.println("movement" + String(maxReading) + " > Read Value: " + String(tempReading)  );
    updateSolarPanel();
    globalInit == true;
   
  }
  else{
    Serial.println("No movement" + String(maxReading) + " < Read Value: " + String(tempReading)  );
  }
 */ 
  //ReadCurrentSensor();
  //Check every 5 secs
  updateSolarPanel();
  delay(5000);
}
void updateSolarPanel(){
  int cSteps = 0;
  int cCSteps = 0;



  if(posData.init == true){
    if(!posData.skipClockwise){
      Serial.println("Skipping CounterClockwise");
      Clockwise();
      posData.init = false;
    }
    else{
      Serial.println("Skipping Clockwise");
      CounterClockwise();
      posData.init = false;
    }
  }
  else{
    cSteps = Clockwise();
    cCSteps = CounterClockwise();
    posData.init = true;
  }

  if((cSteps > cCSteps) && (posData.init)){
    posData.skipClockwise = false;
    posData.skipCounterClockwise = true;
    Serial.println("More steps clockwise cSteps: " + String(cSteps) + " > cCSteps: " +  String(cCSteps));

  }
  else if(posData.init){
    posData.skipClockwise = true;
    posData.skipCounterClockwise = false;
    Serial.println("More steps counterclockwise Steps: " + String(cSteps) + " < cCSteps: " +  String(cCSteps));
  }

//Check for almost full rotation and untangle cord
  if(abs(posData.totalSteps)>2048 ){ //(2048 = 360 degrees)
    while(posData.totalSteps!=0){ //0 = starting position
      if(posData.totalSteps<0){ // Rotated more than -360 step counterclockwise
        posData.totalSteps++;
        myStepper.step(1); 
      }
      else{// Rotated more than 360 step clockwise
        posData.totalSteps--;
        myStepper.step(-1);
      }
    }
    
  }
  
}

int Clockwise(){
    //Keep track of steps for while loop
  int ClockwiseSteps = 0;
  //Interval that determines a sensor check
  int stepInterval = startingSteps;
  //The counter that, when equal to stepinterval allows a sensor check condition (resets to zero after condition is met)
  int stepIntervalCount = 0;
  //Allows an initial loop to pass to get old and new readings
  bool init = false;
  //(new sum of readings - old sum of readings)/stepInterval
  float rateOfIncrease = 0;
  //rateOfIncrease, stored after each loop
  float oldRateOfIncrease =0;
  //new sum of readings
  float sumofData =0;
  float oldsumofData = 0;

  //update readings, initialize old readings
  ReadCurrentSensor();
  avgPower.oldCurrent = avgPower.current;
  avgPower.oldVoltage = avgPower.loadVoltage;
  avgPower.oldPower = avgPower.power;

  //Clockwise loop (1024 steps = 180 degrees)

  while (stepInterval > 2 && ClockwiseSteps < 1024){
    //Clockwise movement (-1) Counterclockwise movement (1)
    myStepper.step(-1);
    //Keep track of local steps
    ClockwiseSteps++;
    //Keep track of global steps (for untangle cord function)
    posData.totalSteps--;
    //Increment step interval count, for sensor check condition
    stepIntervalCount++;

    //When stepIntervalCount matches the stepInterval, run the sensor check
    if(stepIntervalCount == stepInterval){
      //Reset stepIntervalCount
      stepIntervalCount = 0;
      //Get new readings
      ReadCurrentSensor();
      //Update the sumofData
      sumofData = (avgPower.current+avgPower.loadVoltage+(avgPower.power*2));
      rateOfIncrease = (sumofData - oldsumofData)/stepInterval;

      //check if the loop has initialized
      if(init){
        //The panel is moving and the readings are increasing at a faster rate than before, gradually increase the stepInterval to move the motor a bit more. The next check will be later.
        if(rateOfIncrease >= oldRateOfIncrease){
          stepInterval = stepInterval+addSteps;
        }
        //readings are not increasing at a faster rate
        else{
          if(rateOfIncrease > 0){
            stepInterval = stepInterval;
          }
          else{
            stepInterval = stepInterval/divideSteps;
          }

        }
      }
      //Print log debug
      Serial.print("rate of increase "); Serial.println(rateOfIncrease,6);
      Serial.print("old rate of increase "); Serial.println(oldRateOfIncrease,6);
      Serial.print("sumOfData "); Serial.println(sumofData,6);
      Serial.print("sumOfData Equation "); Serial.println("power: "+ String(avgPower.power) +" + current:"+ String(avgPower.current) +" + Lvoltage"+ String(avgPower.loadVoltage) + "/" + String(stepInterval));
      Serial.print("oldsumofData "); Serial.println(oldsumofData,6);
      
      //Set the old readings to the new ones for this check
      oldRateOfIncrease = rateOfIncrease;
      oldsumofData = sumofData;
      avgPower.oldCurrent = avgPower.current;
      avgPower.oldVoltage = avgPower.loadVoltage;
      avgPower.oldPower = avgPower.power;
      init = true;
      if(posData.maxReading < sumofData){
        posData.maxReading = sumofData;
      }

    }
    
  }
  return ClockwiseSteps;
}


int CounterClockwise(){
  //CounterClockwise (Same as above opposite direction)

  int counterClockwiseSteps = 0;
  int stepInterval = startingSteps;
  int stepIntervalCount = 0;
  bool init = false;
  float rateOfIncrease = 0;
  float oldRateOfIncrease =0;
  //new sum of readings
  float sumofData =0;
  float oldsumofData = 0;

  ReadCurrentSensor();
  avgPower.oldCurrent = avgPower.current;
  avgPower.oldVoltage = avgPower.loadVoltage;
  avgPower.oldPower = avgPower.power;

  while (stepInterval > 2 && counterClockwiseSteps < 1024){
    //Clockwise movement (-1) Counterclockwise movement (1)
    myStepper.step(1);
    //Keep track of local steps
    counterClockwiseSteps++;
    //Keep track of global steps (for untangle cord function)
    posData.totalSteps++;
    //Increment step interval count, for sensor check condition
    stepIntervalCount++;

    //When stepIntervalCount matches the stepInterval, run the sensor check
    if(stepIntervalCount == stepInterval){
      //Reset stepIntervalCount
      stepIntervalCount = 0;
      //Get new readings
      ReadCurrentSensor();
      //Update the sumofData
      sumofData = (avgPower.current+avgPower.loadVoltage+(avgPower.power*2));
      rateOfIncrease = (sumofData - oldsumofData)/stepInterval;

      //check if the loop has initialized
      if(init){
        //The panel is moving and the readings are increasing at a faster rate than before, gradually increase the stepInterval to move the motor a bit more. The next check will be later.
        if(rateOfIncrease >= oldRateOfIncrease){
          stepInterval = stepInterval+addSteps;
        }
        //readings are not increasing at a faster rate
        else{
          if(rateOfIncrease > 0){
            stepInterval = stepInterval;
          }
          else{
            stepInterval = stepInterval/divideSteps;
          }

        }
      }
      //Print log debug
      Serial.print("rate of increase "); Serial.println(rateOfIncrease,6);
      Serial.print("old rate of increase "); Serial.println(oldRateOfIncrease,6);
      Serial.print("sumOfData "); Serial.println(sumofData,6);
      Serial.print("sumOfData Equation "); Serial.println("power: "+ String(avgPower.power) +" + current:"+ String(avgPower.current) +" + Lvoltage"+ String(avgPower.loadVoltage) + "/" + String(stepInterval));
      Serial.print("oldsumofData "); Serial.println(oldsumofData,6);

      //Set the old readings to the new ones for this check
      oldRateOfIncrease = rateOfIncrease;
      oldsumofData = sumofData;
      avgPower.oldCurrent = avgPower.current;
      avgPower.oldVoltage = avgPower.loadVoltage;
      avgPower.oldPower = avgPower.power;
      init = true;
      if(posData.maxReading < sumofData){
        posData.maxReading = sumofData;
      }

      

    }

    
  }
  return counterClockwiseSteps;
}

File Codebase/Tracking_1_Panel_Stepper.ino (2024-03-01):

#include <Stepper.h>
#include <Wire.h>
#include <Adafruit_INA219.h>

#define STEPPER_PIN_1 8
#define STEPPER_PIN_2 9
#define STEPPER_PIN_3 10
#define STEPPER_PIN_4 11

const int stepsPerRevolution = 2048;
Stepper myStepper(stepsPerRevolution, 8, 10, 9, 11);

int MotorSpeed = 5;
Adafruit_INA219 ina219;

float lastCurrent;
float lastVoltage;
bool rightcheck;
bool leftcheck;
bool increase;


unsigned long time = millis();


void setup(void) 
{
  Serial.begin(9600);

  //pinMode(STEPPER_PIN_1, OUTPUT);
  //pinMode(STEPPER_PIN_2, OUTPUT);
  //pinMode(STEPPER_PIN_3, OUTPUT);
  //pinMode(STEPPER_PIN_4, OUTPUT);
  myStepper.setSpeed(1);

  while (!Serial) {
      // will pause Zero, Leonardo, etc until serial console opens
      delay(1);
  }
    
  Serial.println("Hello!");
  
  // Initialize the INA219.
  // By default the initialization will use the largest range (32V, 2A).  However
  // you can call a setCalibration function to change this range (see comments).
  if (! ina219.begin()) {
    Serial.println("Failed to find INA219 chip");
    while (1) { delay(10); }
  }
  // To use a slightly lower 32V, 1A range (higher precision on amps):
  //ina219.setCalibration_32V_1A();
  // Or to use a lower 16V, 400mA range (higher precision on volts and amps):
  ina219.setCalibration_16V_400mA();
  

  Serial.println("Measuring voltage and current with INA219 ...");
}

void loop(void) 
{


  float shuntvoltage = 0;
  float busvoltage = 0;
  float current_mA = 0;
  float loadvoltage = 0;
  float power_mW = 0;

  float avgLoadVoltage = 0;
  float avgCurrent = 0;
  float samplesC =0, samplesV =0;


  shuntvoltage = ina219.getShuntVoltage_mV();
  busvoltage = ina219.getBusVoltage_V();
  current_mA = ina219.getCurrent_mA();
  power_mW = ina219.getPower_mW();
  loadvoltage = busvoltage + (shuntvoltage / 1000);



  for (int x = 0; x < 150; x++){ //Get 150 samples
    shuntvoltage = ina219.getShuntVoltage_mV();
    busvoltage = ina219.getBusVoltage_V();
    current_mA = ina219.getCurrent_mA();
    power_mW = ina219.getPower_mW();
    loadvoltage = busvoltage + (shuntvoltage / 1000);
 
    samplesC = samplesC + current_mA;  //Add samples together
    samplesV = samplesV + loadvoltage;
  }
  avgLoadVoltage = samplesV/150.000;//Taking Average of Samples
  avgCurrent = samplesC/150.000;
  
  Serial.print("Bus Voltage:   "); Serial.print(busvoltage); Serial.println(" V");
  Serial.print("Shunt Voltage: "); Serial.print(shuntvoltage); Serial.println(" mV");
  Serial.print("Load Voltage:  "); Serial.print(avgLoadVoltage); Serial.println(" V");
  Serial.print("Current:       "); Serial.print(avgCurrent); Serial.println(" mA");
  Serial.print("Power:         "); Serial.print(power_mW); Serial.println(" mW");
  Serial.println("");

  move(avgCurrent, avgLoadVoltage);
  lastCurrent = avgCurrent;
  lastVoltage = avgLoadVoltage;
  delay(10000);
}
void move(float newCurrent, float newVoltage){
  int steps = 0;
  increase = false;
  
  while (increase == false && steps < 500){
    myStepper.step(-1);
    steps++;
    if(ina219.getCurrent_mA()< lastCurrent && ina219.getBusVoltage_V() < lastVoltage){
      increase = false;
    }
    if(ina219.getCurrent_mA() > lastCurrent && ina219.getBusVoltage_V() > lastVoltage){
      increase = true;
    }

    //Serial.print("New Current:       "); Serial.print(newCurrent); Serial.print(" Last Current:       "); Serial.println(lastCurrent);
    //Serial.print("New Voltage:       "); Serial.print(newVoltage); Serial.print(" Last Voltage:       "); Serial.println(lastVoltage);
    delay(10);
  }
  steps = 0;
  while (increase == false && steps < 500){
    myStepper.step(1);
    steps++;
    if(ina219.getCurrent_mA() < lastCurrent && ina219.getBusVoltage_V() < lastVoltage){
      increase = false;
    }
    if(ina219.getCurrent_mA() > lastCurrent && ina219.getBusVoltage_V() > lastVoltage){
      increase = true;
    }

    //Serial.print("New Current:       "); Serial.print(newCurrent); Serial.print(" Last Current:       "); Serial.println(lastCurrent);
    //Serial.print("New Voltage:       "); Serial.print(newVoltage); Serial.print(" Last Voltage:       "); Serial.println(lastVoltage);
    delay(10);
  }
  
  
}

void clockwise(){
 //1
  digitalWrite(STEPPER_PIN_4, LOW);
  digitalWrite(STEPPER_PIN_3, LOW);
  digitalWrite(STEPPER_PIN_2, LOW);
  digitalWrite(STEPPER_PIN_1, HIGH);
  delay(MotorSpeed);
  //2
  digitalWrite(STEPPER_PIN_4, LOW);
  digitalWrite(STEPPER_PIN_3, LOW);
  digitalWrite(STEPPER_PIN_2, HIGH);
  digitalWrite(STEPPER_PIN_1, HIGH);
  delay(MotorSpeed);
  //3
  digitalWrite(STEPPER_PIN_4, LOW);
  digitalWrite(STEPPER_PIN_3, LOW);
  digitalWrite(STEPPER_PIN_2, HIGH);
  digitalWrite(STEPPER_PIN_1, LOW);
  delay(MotorSpeed);
  //4
  digitalWrite(STEPPER_PIN_4, LOW);
  digitalWrite(STEPPER_PIN_3, HIGH);
  digitalWrite(STEPPER_PIN_2, HIGH);
  digitalWrite(STEPPER_PIN_1, LOW);
  delay(MotorSpeed);
  //5
  digitalWrite(STEPPER_PIN_4, LOW);
  digitalWrite(STEPPER_PIN_3, HIGH);
  digitalWrite(STEPPER_PIN_2, LOW);
  digitalWrite(STEPPER_PIN_1, LOW);
  delay(MotorSpeed);
  //6
  digitalWrite(STEPPER_PIN_4, HIGH);
  digitalWrite(STEPPER_PIN_3, HIGH);
  digitalWrite(STEPPER_PIN_2, LOW);
  digitalWrite(STEPPER_PIN_1, LOW);
  delay(MotorSpeed);
  //7
  digitalWrite(STEPPER_PIN_4, HIGH);
  digitalWrite(STEPPER_PIN_3, LOW);
  digitalWrite(STEPPER_PIN_2, LOW);
  digitalWrite(STEPPER_PIN_1, LOW);
  delay(MotorSpeed);
  //8
  digitalWrite(STEPPER_PIN_4, HIGH);
  digitalWrite(STEPPER_PIN_3, LOW);
  digitalWrite(STEPPER_PIN_2, LOW);
  digitalWrite(STEPPER_PIN_1, HIGH);
  delay(MotorSpeed);
}
void counterclockwise(){
  //1
  digitalWrite(STEPPER_PIN_4, HIGH);
  digitalWrite(STEPPER_PIN_3, LOW);
  digitalWrite(STEPPER_PIN_2, LOW);
  digitalWrite(STEPPER_PIN_1, LOW);
  delay(MotorSpeed);
  //2
  digitalWrite(STEPPER_PIN_4, HIGH);
  digitalWrite(STEPPER_PIN_3, HIGH);
  digitalWrite(STEPPER_PIN_2, LOW);
  digitalWrite(STEPPER_PIN_1, LOW);
  delay(MotorSpeed);
  //3
  digitalWrite(STEPPER_PIN_4, LOW);
  digitalWrite(STEPPER_PIN_3, HIGH);
  digitalWrite(STEPPER_PIN_2, LOW);
  digitalWrite(STEPPER_PIN_1, LOW);
  delay(MotorSpeed);
  //4
  digitalWrite(STEPPER_PIN_4, LOW);
  digitalWrite(STEPPER_PIN_3, HIGH);
  digitalWrite(STEPPER_PIN_2, HIGH);
  digitalWrite(STEPPER_PIN_1, LOW);
  delay(MotorSpeed);
  //5
  digitalWrite(STEPPER_PIN_4, LOW);
  digitalWrite(STEPPER_PIN_3, LOW);
  digitalWrite(STEPPER_PIN_2, HIGH);
  digitalWrite(STEPPER_PIN_1, LOW);
  delay(MotorSpeed);
  //6
  digitalWrite(STEPPER_PIN_4, LOW);
  digitalWrite(STEPPER_PIN_3, LOW);
  digitalWrite(STEPPER_PIN_2, HIGH);
  digitalWrite(STEPPER_PIN_1, HIGH);
  delay(MotorSpeed);
  //7
  digitalWrite(STEPPER_PIN_4, LOW);
  digitalWrite(STEPPER_PIN_3, LOW);
  digitalWrite(STEPPER_PIN_2, LOW);
  digitalWrite(STEPPER_PIN_1, HIGH);
  delay(MotorSpeed);
  //8
  digitalWrite(STEPPER_PIN_4, HIGH);
  digitalWrite(STEPPER_PIN_3, LOW);
  digitalWrite(STEPPER_PIN_2, LOW);
  digitalWrite(STEPPER_PIN_1, HIGH);
  delay(MotorSpeed);
}

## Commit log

2023-11-21 Create Circuit Designs
2023-11-21 Create ICA Destry Cable
2023-11-21 Update ICA Destry Cable
2024-02-10 Create 3D Printed Housing Setup
2024-02-10 Rename 3D Printed Housing Setup to 3D Printed Housing Setup.md
2024-02-10 Update 3D Printed Housing Setup.md
2024-02-15 Added current testing sketch file
    ACS712 testing sketch file. (C++)
2024-03-14 Better tracking algorithm
    Smarter tracking will check 180 degrees both directions, feedback will slow the movement as it approaches a strong light source. Checks both directions every update (10s) direction bias will be added next to eliminate a direction. This will fix oscillation.
    [Tracking_2_Panel_Stepper_Enhanced_Bidirectional.ino]
2024-03-23 Added updated circuit diagrams
2024-03-23 Create Circuit Descriptions.md
2024-03-23 Update Circuit Descriptions.md
2024-03-23 Tweaked overlapping wiring in various circuit diagrams
2024-03-23 Added 3D Printer Content
    - Wire frame pictures
    - Rendered pictures
    - stl print file
    [Solar_Panel_Mount_Final_2.stl]
2024-04-14 Update README.md
    Updated circuit links
2024-04-15 Rename ICA Destry Cable to ICA Destry Cable.md
2024-04-15 Update ICA Destry Cable.md
2024-04-15 Rename Test Cases.pdf to Test Cases (OLD SERVO MOTORS).pdf
2024-04-15 Rename Test Cases (OLD SERVO MOTORS).pdf to Test Cases (OUTDATED).pdf
2024-04-15 Create Destry Cable SA.md
2024-04-15 Update Destry Cable SA.md
